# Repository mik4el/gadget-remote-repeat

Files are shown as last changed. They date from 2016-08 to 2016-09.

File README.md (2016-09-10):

# Remote repeat
Repeats IR remote signals received at e.g. a TV to a connected IR LED connected to a long wire placed e.g. inside a cabinet. This is also a minimal footprint platform to receive standard IR signals, manipulate them and to send standard IR signals.

## Hardware
The hardware consists of a standard IR receiver (TSOP38238) and an Attiny85 to process the signal and to control sending a new signal. The application is powered by USB micro from e.g. the USB output from a TV.

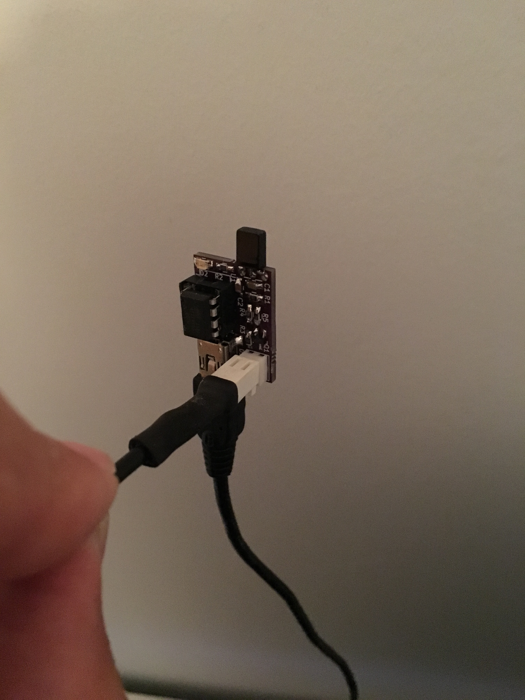
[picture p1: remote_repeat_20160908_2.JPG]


The pcb, where more details can be found in the hardware folder, is a minimal two layer pcb for the application. The top view of the current pcb can be viewed below:

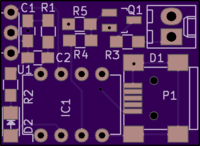
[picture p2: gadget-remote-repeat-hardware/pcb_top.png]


## Software dependencies
The software is based on Arduino and uses the external library tiny_IRremote adopted by https://github.com/SeeJayDee from the popular https://github.com/z3t0/Arduino-IRremote library. I have made modifications to the library to be even smaller for the current usage. The modified library is in ```gadget-remote-repeat-tiny```. To include the current library please follow e.g. https://www.arduino.cc/en/Guide/Libraries to install an external library.

## Structure of repo
For an Attiny85 version of the software, please see ```gadget-remote-repeat-tiny```. For other Arduino platforms please see ```gadget-remote-repeat```.

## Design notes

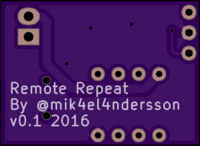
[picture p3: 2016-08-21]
gadget-remote-repeat-hardware/pcb_bottom.png

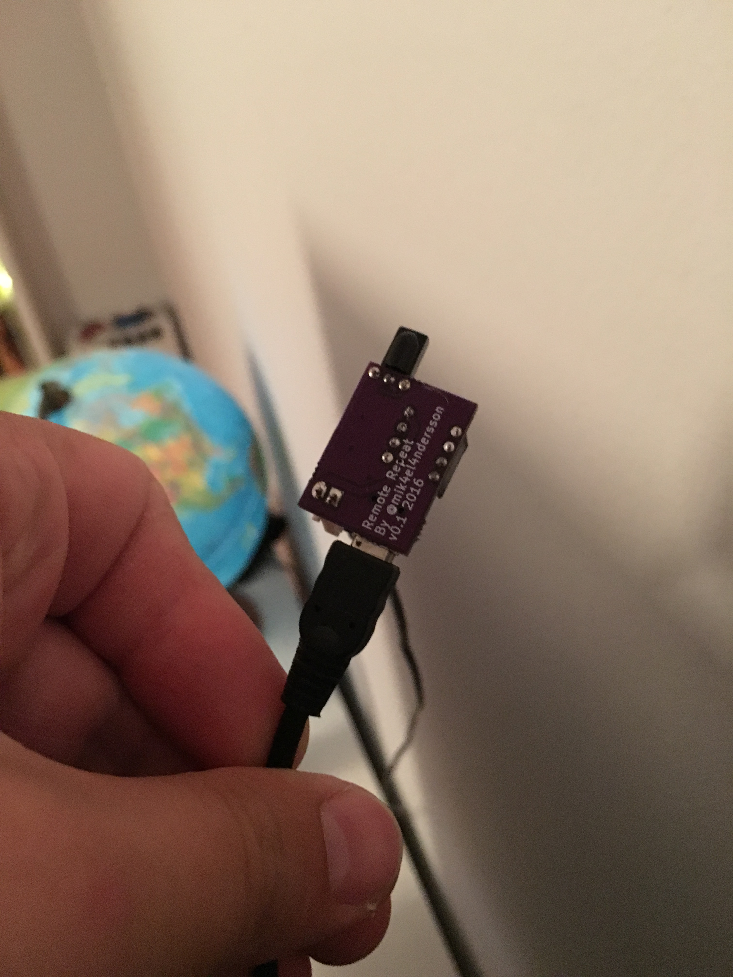
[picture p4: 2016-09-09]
remote_repeat_20160908_1.JPG

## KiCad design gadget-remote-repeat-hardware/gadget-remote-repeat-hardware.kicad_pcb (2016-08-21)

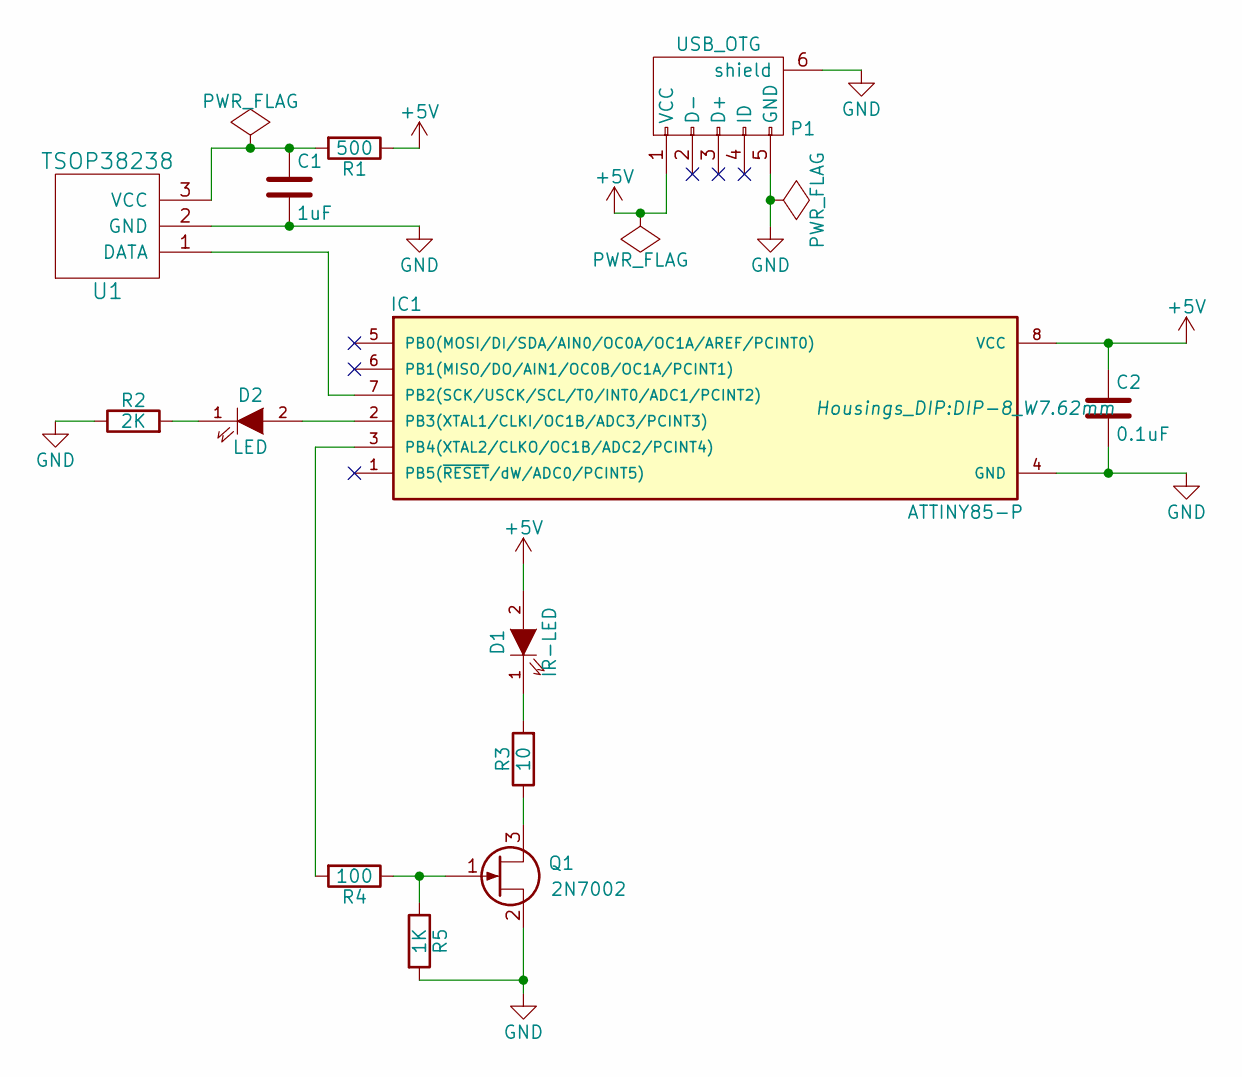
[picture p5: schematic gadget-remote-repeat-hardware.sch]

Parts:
C1: 1uF; C_0805_HandSoldering
C2: 0.1uF; C_0805_HandSoldering
D1: IR-LED; Molex_KK-6410-02_02x2.54mm_Straight
D2: LED; LED_1206
IC1: ATTINY85-P; DIP-8_W7.62mm
P1: USB_OTG; USB_Mini-B
Q1: 2N7002; SOT-23_Handsoldering
R1: 500; R_0805_HandSoldering
R2: 2K; R_0805_HandSoldering
R3: 10; R_0805_HandSoldering
R4: 100; R_0805_HandSoldering
R5: 1K; R_0805_HandSoldering
U1: TSOP38238

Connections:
+5V: C2.1, D1.2 (A), IC1.8 (VCC), P1.1 (VCC), R1.1
GND: C1.2, C2.2, IC1.4 (GND), P1.5 (GND), P1.6 (shield), Q1.2 (S), R2.1, R5.2, U1.2 (GND)
unnamed: C1.1, R1.2, U1.3 (VCC)
unnamed: D1.1 (K), R3.2
unnamed: D2.1 (K), R2.2
unnamed: D2.2 (A), IC1.2 (PB3(XTAL1/CLKI/OC1B/ADC3/PCINT3))
unnamed: IC1.3 (PB4(XTAL2/CLKO/OC1B/ADC2/PCINT4)), R4.2
unnamed: IC1.7 (PB2(SCK/USCK/SCL/T0/INT0/ADC1/PCINT2)), U1.1 (DATA)
unnamed: Q1.1 (G), R4.1, R5.1
unnamed: Q1.3 (D), R3.1

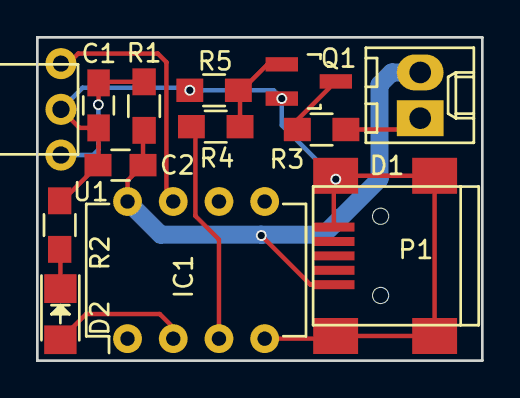
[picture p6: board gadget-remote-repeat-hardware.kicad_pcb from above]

Board: 2 copper layers, 24.7 x 18.0 mm, 13 parts (0 on the bottom side), 10 nets.

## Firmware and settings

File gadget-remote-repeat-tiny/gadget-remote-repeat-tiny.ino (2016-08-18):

#include <tiny_IRremote.h>

#define STATUS_PIN 3
#define RECEIVE_PIN 2
#define KHZ 38 // observed that 38 gives closer to 38.5kHz carrier which remote uses on attiny85
//Nano send pin 3

IRrecv irrecv(RECEIVE_PIN);
IRsend irsend;
decode_results results;

// Storage for the recorded code
unsigned int rawCodes[RAWBUF]; // The durations if raw
int codeLen; // The length of the code

void setup() {
  irrecv.enableIRIn();  // Start the receiver
  pinMode(STATUS_PIN, OUTPUT);
}

void storeCode(decode_results *results) {
  int count = results->rawlen;
  codeLen = results->rawlen;
  // To store raw codes:
  // Drop first value (gap)
  // Convert from ticks to microseconds
  // Tweak marks shorter, and spaces longer to cancel out IR receiver distortion
  for (int i = 1; i <= codeLen; i++) {
    if (i % 2) {
      // Mark
      rawCodes[i - 1] = results->rawbuf[i]*USECPERTICK - MARK_EXCESS;
    } 
    else {
      // Space
      rawCodes[i - 1] = results->rawbuf[i]*USECPERTICK + MARK_EXCESS;
    }
  }
}

void sendCode() {
  irsend.sendRaw(rawCodes, codeLen, KHZ);
  irrecv.enableIRIn();
}

void sendSamsungPowerCode() {
  /*
   * Samsung power on
   * unsigned int data = 0xE0E040BF;
   * For debug purposes.
  */
  unsigned int rawData[67] = {4400,4450, 550,1650, 550,1650, 550,1700, 550,550, 550,550, 550,550, 550,550, 550,550, 600,1650, 500,1700, 550,1650, 550,550, 550,550, 550,600, 550,550, 550,550, 550,550, 550,1650, 550,550, 650,500, 500,600, 550,550, 550,550, 550,550, 550,1650, 550,550, 550,1700, 550,1650, 600,1600, 550,1700, 550,1650, 550,1650, 550};  // SAMSUNG E0E040BF
  irsend.sendRaw(rawData, sizeof(rawData) / sizeof(rawData[0]), KHZ);
  irrecv.enableIRIn();
}

void loop() {

  if (irrecv.decode(&results)) {  // Grab an IR code
    storeCode(&results);
    irrecv.resume(); 
    digitalWrite(STATUS_PIN, HIGH);
    delay(50);
    digitalWrite(STATUS_PIN, LOW);
    // Prepare for the next value
    sendCode();
  }
  /* Debug
  sendSamsungPowerCode();
  delay(1000);
  */
}

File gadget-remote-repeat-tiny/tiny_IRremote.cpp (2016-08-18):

/*
 * tiny_IRremote
 * Version 0.2 July, 2016
 * Christian D'Abrera
 * Fixed what was originally rather broken code from http://www.gammon.com.au/Arduino/
 * ...itself based on work by Ken Shirriff.
 *
 * This code was tested for both sending and receiving IR on an ATtiny85 DIP-8 chip.
 * IMPORTANT: IRsend only works from PB4 ("pin 4" according to Arduino). You will need to 
 * determine which physical pin this corresponds to for your chip, and connect your transmitter
 * LED there.
 *
 * Copyright 2009 Ken Shirriff
 * For details, see http://arcfn.com/2009/08/multi-protocol-infrared-remote-library.html
 *
 * Interrupt code based on NECIRrcv by Joe Knapp
 * http://www.arduino.cc/cgi-bin/yabb2/YaBB.pl?num=1210243556
 * Also influenced by http://zovirl.com/2008/11/12/building-a-universal-remote-with-an-arduino/
 */

#include "tiny_IRremote.h"
#include "tiny_IRremoteInt.h"

// Provides ISR
#include <avr/interrupt.h>

volatile irparams_t irparams;

// These versions of MATCH, MATCH_MARK, and MATCH_SPACE are only for debugging.
// To use them, set DEBUG in tiny_IRremoteInt.h
// Normally macros are used for efficiency
#ifdef DEBUG
#error debug enabled
int MATCH(int measured, int desired) {
  Serial.print("Testing: ");
  Serial.print(TICKS_LOW(desired), DEC);
  Serial.print(" <= ");
  Serial.print(measured, DEC);
  Serial.print(" <= ");
  Serial.println(TICKS_HIGH(desired), DEC);
  return measured >= TICKS_LOW(desired) && measured <= TICKS_HIGH(desired);
}

int MATCH_MARK(int measured_ticks, int desired_us) {
  Serial.print("Testing mark ");
  Serial.print(measured_ticks * USECPERTICK, DEC);
  Serial.print(" vs ");
  Serial.print(desired_us, DEC);
  Serial.print(": ");
  Serial.print(TICKS_LOW(desired_us + MARK_EXCESS), DEC);
  Serial.print(" <= ");
  Serial.print(measured_ticks, DEC);
  Serial.print(" <= ");
  Serial.println(TICKS_HIGH(desired_us + MARK_EXCESS), DEC);
  return measured_ticks >= TICKS_LOW(desired_us + MARK_EXCESS) && measured_ticks <= TICKS_HIGH(desired_us + MARK_EXCESS);
}

int MATCH_SPACE(int measured_ticks, int desired_us) {
  Serial.print("Testing space ");
  Serial.print(measured_ticks * USECPERTICK, DEC);
  Serial.print(" vs ");
  Serial.print(desired_us, DEC);
  Serial.print(": ");
  Serial.print(TICKS_LOW(desired_us - MARK_EXCESS), DEC);
  Serial.print(" <= ");
  Serial.print(measured_ticks, DEC);
  Serial.print(" <= ");
  Serial.println(TICKS_HIGH(desired_us - MARK_EXCESS), DEC);
  return measured_ticks >= TICKS_LOW(desired_us - MARK_EXCESS) && measured_ticks <= TICKS_HIGH(desired_us - MARK_EXCESS);
}
#endif

void IRsend::sendRaw(unsigned int buf[], int len, int hz)
{
  enableIROut(hz);
  for (int i = 0; i < len; i++) {
    if (i & 1) {
      space(buf[i]);
    } 
    else {
      mark(buf[i]);
    }
  }
  space(0); // Just to be sure
}

void IRsend::mark(int time) {
  // Sends an IR mark for the specified number of microseconds.
  // The mark output is modulated at the PWM frequency.
  GTCCR |= _BV(COM1B1); // Enable pin 3 PWM output (PB4 - Arduino D4)
  delayMicroseconds(time);
}

/* Leave pin off for time (given in microseconds) */
void IRsend::space(int time) {
  // Sends an IR space for the specified number of microseconds.
  // A space is no output, so the PWM output is disabled.
  GTCCR &= ~(_BV(COM1B1)); // Disable pin 3 PWM output (PB4 - Arduino D4)
  delayMicroseconds(time);
}

void IRsend::enableIROut(int khz) {
  // Enables IR output.  The khz value controls the modulation frequency in kilohertz.
  // The IR output will be on pin 3 (PB4 - Arduino D4) (OC1B).
  // This routine is designed for 36-40KHz; if you use it for other values, it's up to you
  // to make sure it gives reasonable results.  (Watch out for overflow / underflow / rounding.)
  // TIMER1 is used in fast PWM mode, with OCR1Ccontrolling the frequency and OCR1B
  // controlling the duty cycle.
  // There is no prescaling, so the output frequency is 8MHz / (2 * OCR1C)
  // To turn the output on and off, we leave the PWM running, but connect and disconnect the output pin.
  // A few hours staring at the ATmega documentation and this will all make sense.
  // See my Secrets of Arduino PWM at http://arcfn.com/2009/07/secrets-of-arduino-pwm.html for details.

  
  // Disable the Timer1 Interrupt (which is used for receiving IR)
  TIMSK &= ~_BV(TOIE1); //Timer1 Overflow Interrupt

  
  pinMode(4, OUTPUT);  // (PB4 - Arduino D4 - physical pin 3)
  digitalWrite(4, LOW); // When not sending PWM, we want it low
  

  // CTC1 = 1: TOP value set to OCR1C
  // CS = 0001: No Prescaling
  TCCR1 = _BV(CTC1) | _BV(CS10);
  
  // PWM1B = 1: Enable PWM for OCR1B
  GTCCR = _BV(PWM1B);

  // The top value for the timer.  The modulation frequency will be SYSCLOCK / OCR1C.
  OCR1C = SYSCLOCK / khz / 1000;
  OCR1B = OCR1C / 3; // 33% duty cycle

}

IRrecv::IRrecv(int recvpin)
{
  irparams.recvpin = recvpin;
}

// initialization
void IRrecv::enableIRIn() {
  // setup pulse clock timer interrupt
  GTCCR = 0;  // normal, non-PWM mode

  //Prescale /4 (8M/4 = 0.5 microseconds per tick)
  // Therefore, the timer interval can range from 0.5 to 128 microseconds
  // depending on the reset value (255 to 0)
  TCCR1 = _BV(CS11) | _BV(CS10);

  //TIMER1 Overflow Interrupt Enable
  TIMSK |= _BV(TOIE1);




  RESET_TIMER1;

  sei();  // enable interrupts

  // initialize state machine variables
  irparams.rcvstate = STATE_IDLE;
  irparams.rawlen = 0;


  // set pin modes
  pinMode(irparams.recvpin, INPUT);
}
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

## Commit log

2016-08-16 sending power code works
2016-08-21 made pcb and ordered v01
    [gadget-remote-repeat-hardware.kicad_pcb, gadget-remote-repeat-hardware.sch]
